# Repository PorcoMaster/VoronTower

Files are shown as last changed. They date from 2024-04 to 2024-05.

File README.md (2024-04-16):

# Voron Tower
A 4040 frame voron, with the possibility of a box and feet.

Biggest file cannot be uploaded on github, it's on this drive 
https://drive.google.com/file/d/1ePI7Y9nos1gBQOqrRFIDSbPcuf1UqJJw/view?usp=sharing

the file is completely parametric, i had to change the position of the rails, and a bunch of files, any question just ask, i intend to build this printer, so any feedback will be greatly appreciate, it's still some small stuff missing, but for a complete working printer, it should have all files necessary for the modification. 

files that i had to change z belt drive, z idler, z bearing block, zbearing block top, and z bearing block bottom became one, front idler top, front idler bottom, a/b driver, z chain lower mount, panel clip, and door clips. 

i believe the profile i have is the 4040 series 10, but i am not sure. 

i also changed the mgn9 on z to mgn12. i will build the first one as a 350x350, as i don't want to risk a 500x500 with a carriage with 2020, i believe everything else can be used from the original project from voron 2.4.R2

# CLICK ON THE IMAGE TO SEE THE VIDEO!!!

Watch the video (https://www.youtube.com/watch?v=f0kk1qKtl04)
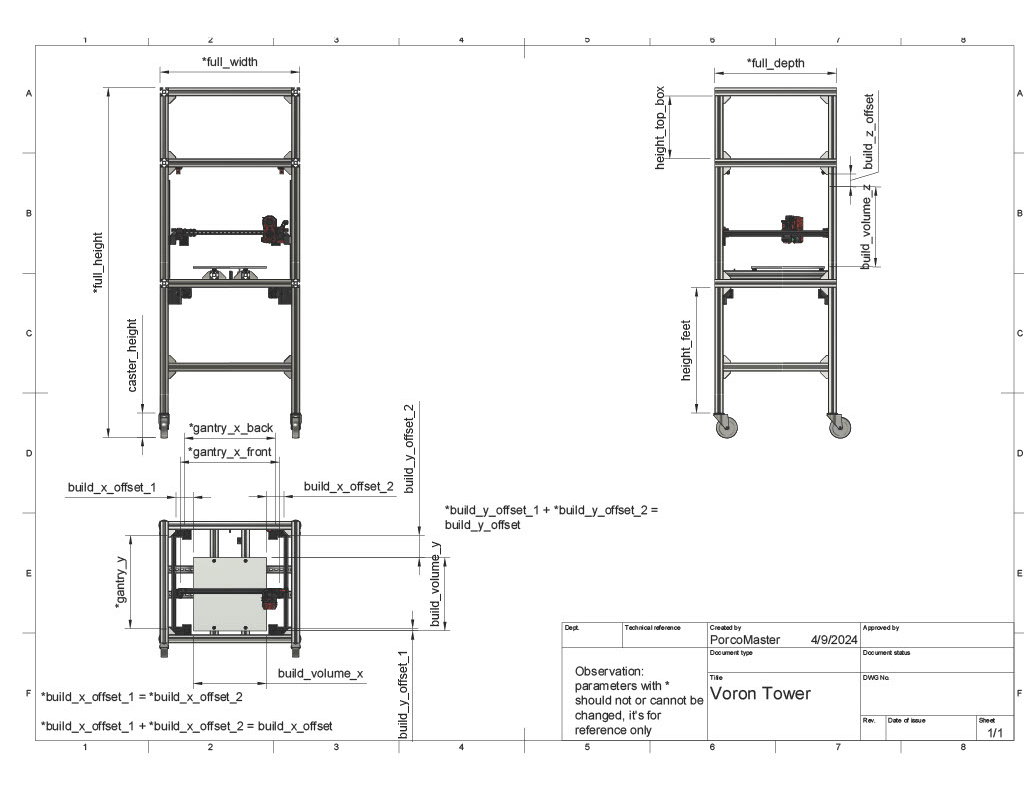
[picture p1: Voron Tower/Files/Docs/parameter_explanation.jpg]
parameters
[]
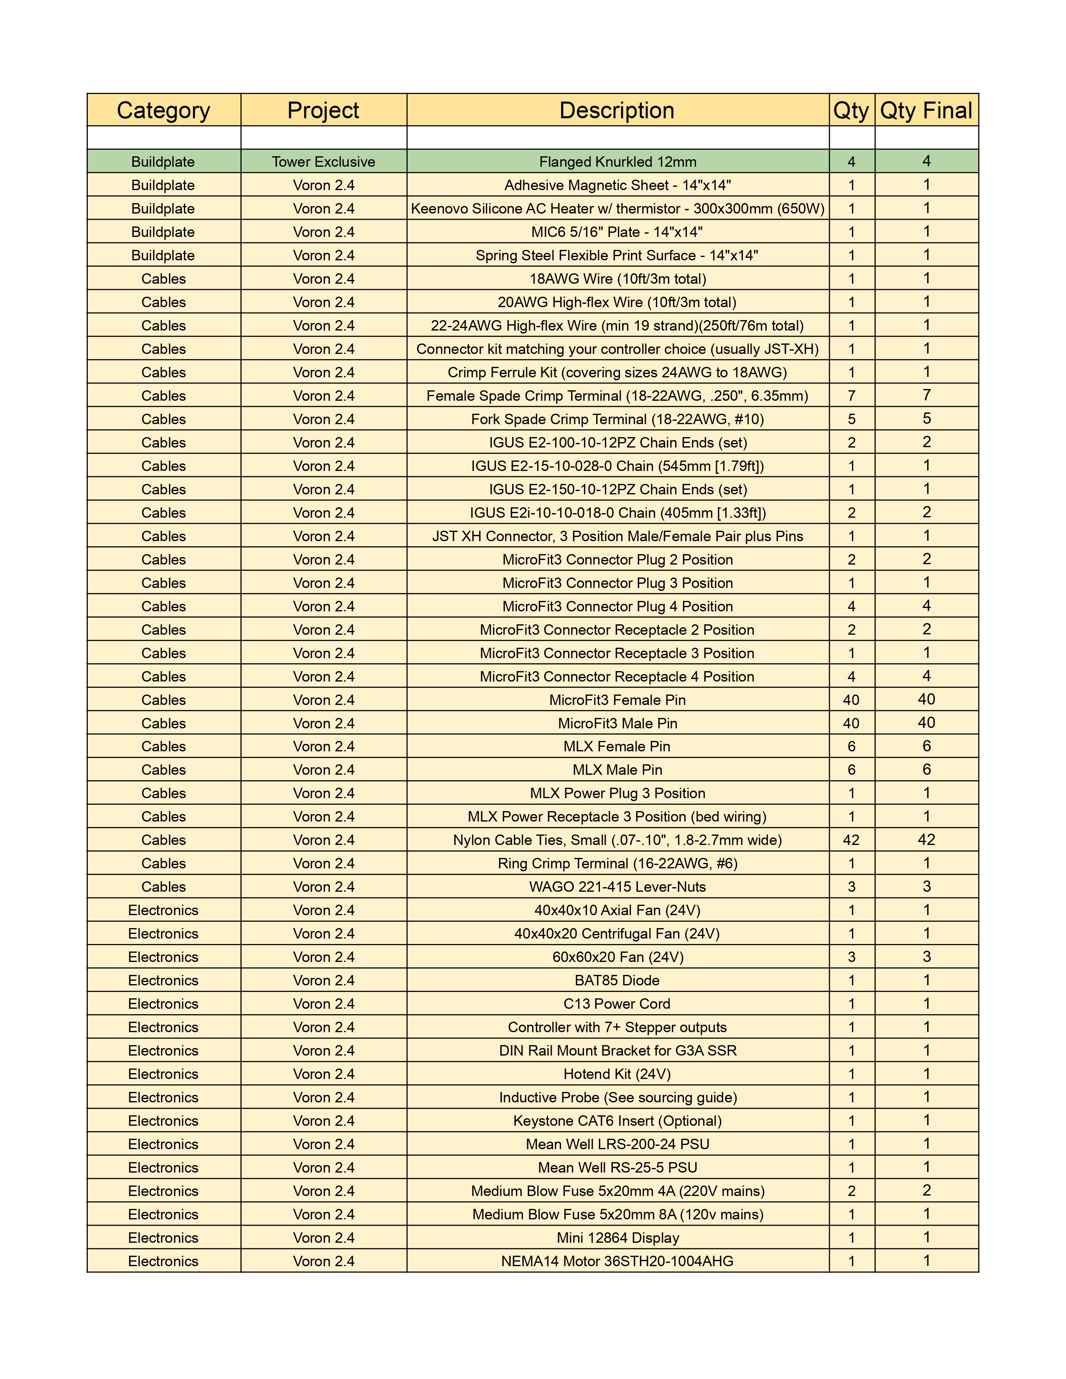
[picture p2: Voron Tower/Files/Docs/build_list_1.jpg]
list_1

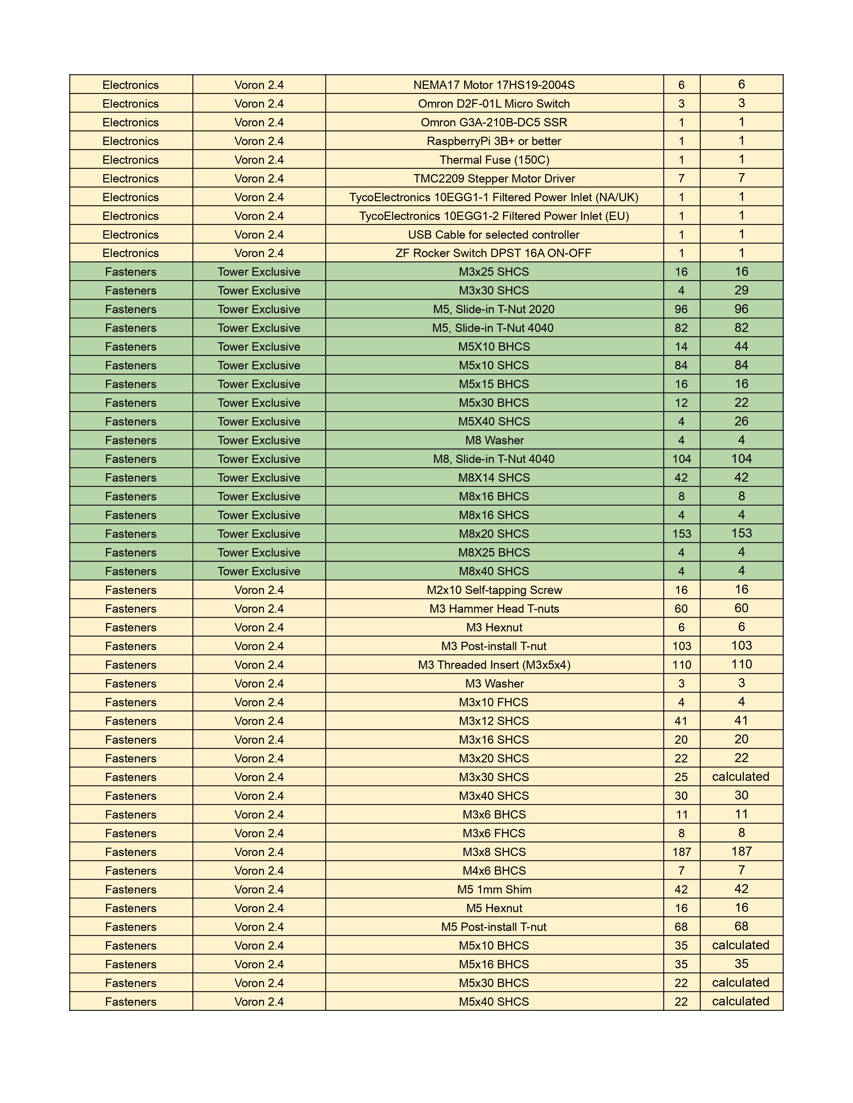
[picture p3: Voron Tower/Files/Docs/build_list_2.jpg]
list_2

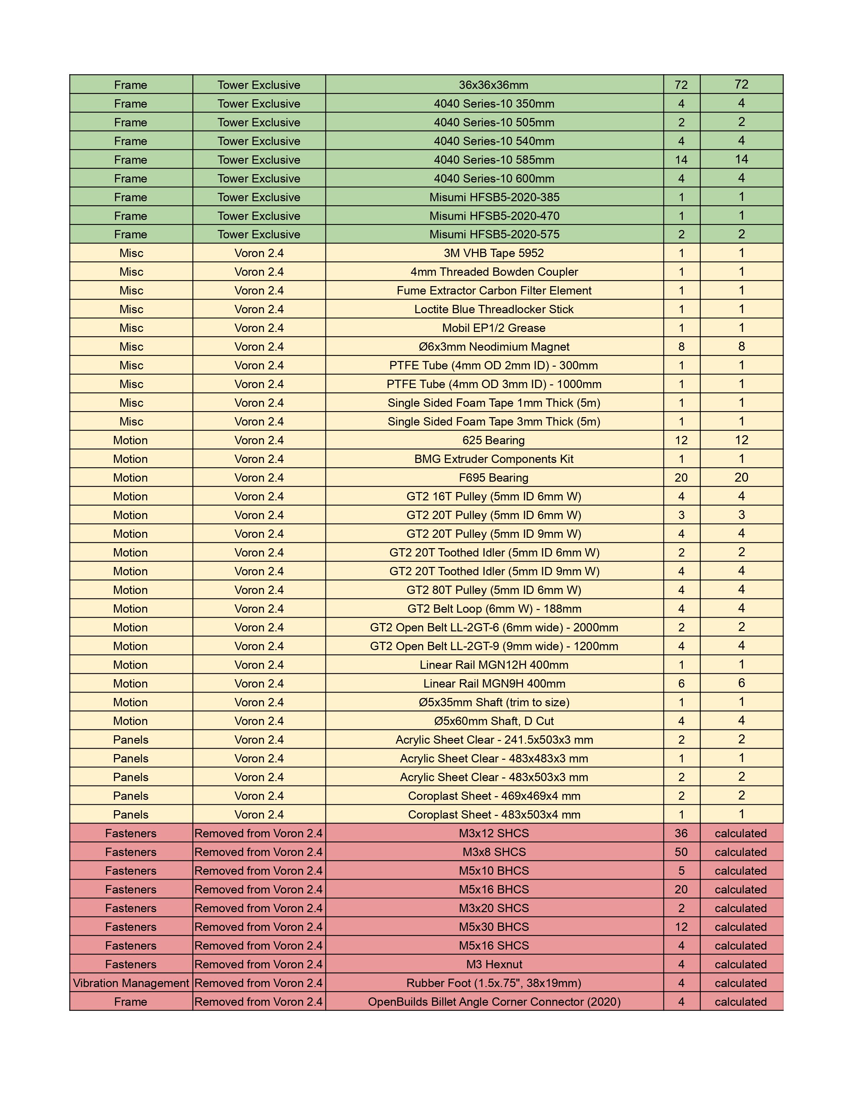
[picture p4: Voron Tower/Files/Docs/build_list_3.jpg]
list_3

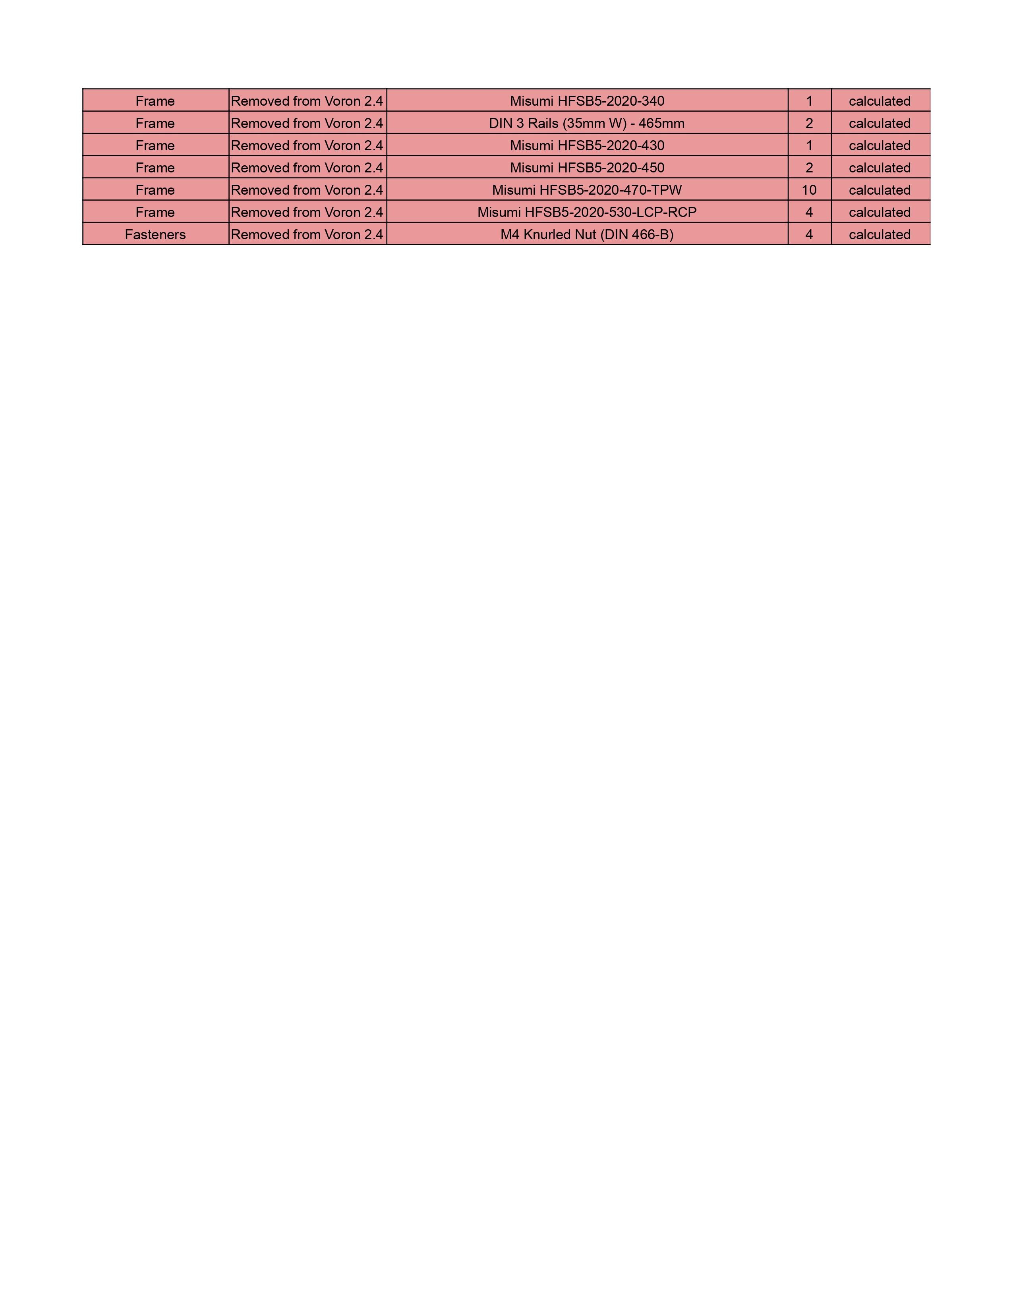
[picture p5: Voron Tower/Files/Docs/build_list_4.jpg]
list_4


#deprecated file: https://drive.google.com/file/d/1OqIFfqwKYdB3r7j7NeKnkWH7O517zN0H/view?usp=sharing

Update: 7 of april of 2024, there are some problems on the build volume and joints on the file, i am fixing it, i will release the fixed files in a few days, will add offset to add in top of the build volume that way you can add freee gantry movement without adding bed, also will add the full height, full width and full depth, also adding caster height to have full height better calculated.

update: 8 of april of 2024, several fixes, fixed all types of joints added some joint animations, i will add a video later on about it, fixed door clips, fixed build volume, put a image of parameter to make it easier to change and understand, added full height, full width, full depth, added build_x_y_z_offset.

update: 15 of april of 2024, a few more joints fixed, this fix are about the size of the gantry profiles, as they do have some work around on then i put up to 6 mm more or less. but you should not change more than 3 mm. if you do want to change change on gantry_x_front, gantry_x_back or gantry_y
also changed the sizes of gantry and overral so all gantrys were on good sizes to be cut, on older one you would find sizes like 572 mm or 673, now i changed so it has easy to cut sizes ending in 0 or 5, ie. 570,475 and so on. 
also changed build_x_offset to 47 mm, build_y_offset to 50 mm and build_z_offset to 24 mm, also i will add my first buy list.

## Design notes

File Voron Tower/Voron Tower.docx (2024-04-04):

Voron Tower

Things that were changed until now

Profiles on frames from 2020 to 4040

mgn12 instead of mgn9 on Z.

I think carriage I choose was mgn12-h, holes are 20mm vertical, and 20mm horizontal apart, center to center

I had to change the place the Z rails were put and to internals on X, instead of Z

Z belt drivers
Z idlers

z bearing block

Z bearing block top

Z bearing Block Bottom

front idler top
front idler bottom

A/B drivers both sides

Z chain lower mount

Panel Clip

door clips

concerns until now, the change of rail location and block top, as they had to be changed on friction or stability to the system

Front Idler A top, could have some improvements but I will let as it is for now, it looks practical, just not beautiful

parameters and projects concerns

I had to add a parameter for mgn_9 so it was easier to make all joints, however, I did not change the parameter on the rectangular pattern of holes in the mgn_9, it will not change anything if it goes wrong practically and on project, but might make it ugly depending on what changes on parameter mgn_9

I am not doing Z_belt cover for now, as I believe the space it has is already small enough, I can do one later thou, as it’s quite easy, I will just focus on other subjects for now.

I will not focus on this now, but later on I need to make a double panel clip for up and down for the box.

the glass I could make one until it get to the top on the sides, and maybe even removing one profile in the middle and making a giant door, or two sections of doors I will analyse this later

just checked, and the build volume is not correct, the Z volume is just 320 mm on the 350mm^3, and the X is 290mm, the Y is correct, but almost none giveaway I think I will give it at least 50 mm of giveway

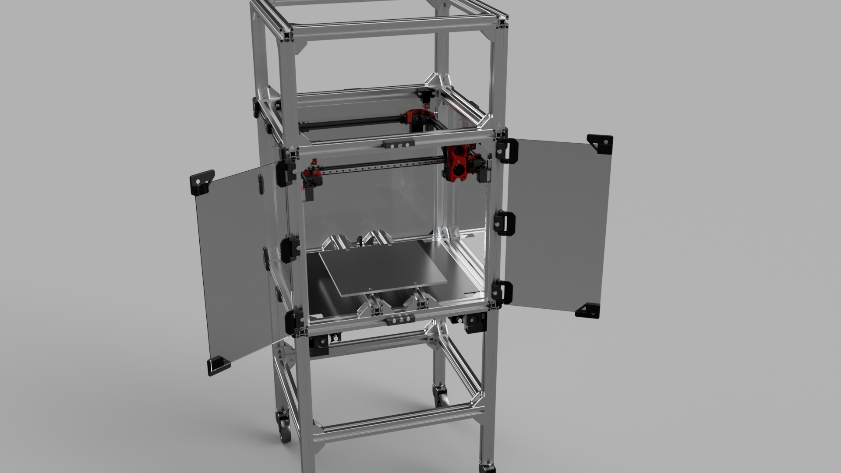
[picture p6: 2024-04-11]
Voron Tower/Files/Docs/Voron_Tower_2024.png

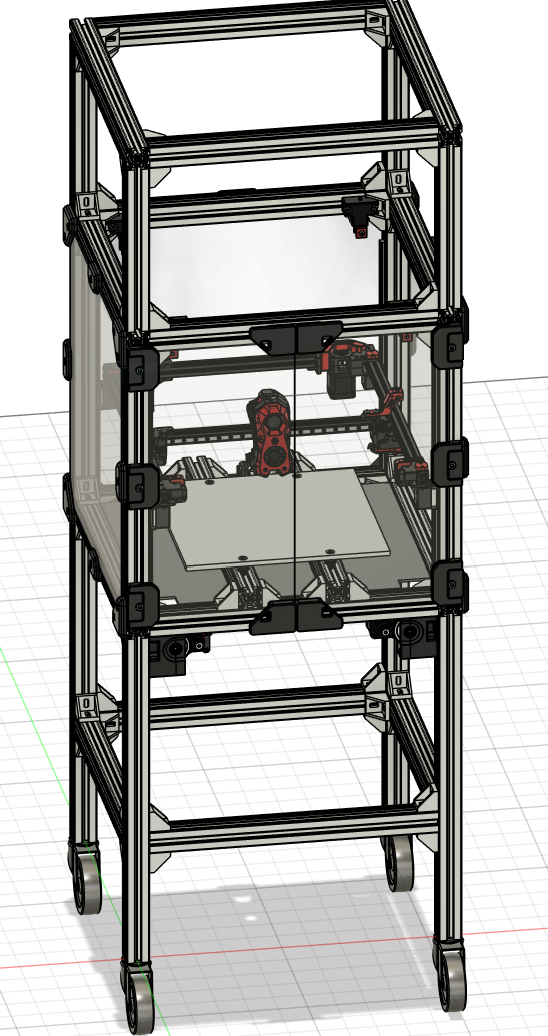
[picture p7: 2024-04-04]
Voron Tower/voron tower.png

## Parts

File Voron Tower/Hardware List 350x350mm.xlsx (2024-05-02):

Category | Project | Description | Qty | Qty Final
Buildplate | Tower Exclusive | Flanged Knurkled 12mm | 4 | 4
Buildplate | Voron 2.4 | Adhesive Magnetic Sheet - 14"x14" | 1 | 1
Buildplate | Voron 2.4 | Keenovo Silicone AC Heater w/ thermistor - 300x300mm (650W) | 1 | 1
Buildplate | Voron 2.4 | MIC6 5/16" Plate - 14"x14" | 1 | 1
Buildplate | Voron 2.4 | Spring Steel Flexible Print Surface - 14"x14" | 1 | 1
Cables | Voron 2.4 | 18AWG Wire (10ft/3m total) | 1 | 1
Cables | Voron 2.4 | 20AWG High-flex Wire (10ft/3m total) | 1 | 1
Cables | Voron 2.4 | 22-24AWG High-flex Wire (min 19 strand)(250ft/76m total) | 1 | 1
Cables | Voron 2.4 | Connector kit matching your controller choice (usually JST-XH) | 1 | 1
Cables | Voron 2.4 | Crimp Ferrule Kit (covering sizes 24AWG to 18AWG) | 1 | 1
Cables | Voron 2.4 | Female Spade Crimp Terminal (18-22AWG, .250", 6.35mm) | 7 | 7
Cables | Voron 2.4 | Fork Spade Crimp Terminal (18-22AWG, #10) | 5 | 5
Cables | Voron 2.4 | IGUS E2-100-10-12PZ Chain Ends (set) | 2 | 2
Cables | Voron 2.4 | IGUS E2-15-10-028-0 Chain (545mm [1.79ft]) | 1 | 1
Cables | Voron 2.4 | IGUS E2-150-10-12PZ Chain Ends (set) | 1 | 1
Cables | Voron 2.4 | IGUS E2i-10-10-018-0 Chain (405mm [1.33ft]) | 2 | 2
Cables | Voron 2.4 | JST XH Connector, 3 Position Male/Female Pair plus Pins | 1 | 1
Cables | Voron 2.4 | MicroFit3 Connector Plug 2 Position | 2 | 2
Cables | Voron 2.4 | MicroFit3 Connector Plug 3 Position | 1 | 1
Cables | Voron 2.4 | MicroFit3 Connector Plug 4 Position | 4 | 4
Cables | Voron 2.4 | MicroFit3 Connector Receptacle 2 Position | 2 | 2
Cables | Voron 2.4 | MicroFit3 Connector Receptacle 3 Position | 1 | 1
Cables | Voron 2.4 | MicroFit3 Connector Receptacle 4 Position | 4 | 4
Cables | Voron 2.4 | MicroFit3 Female Pin | 40 | 40
Cables | Voron 2.4 | MicroFit3 Male Pin | 40 | 40
Cables | Voron 2.4 | MLX Female Pin | 6 | 6
Cables | Voron 2.4 | MLX Male Pin | 6 | 6
Cables | Voron 2.4 | MLX Power Plug 3 Position | 1 | 1
Cables | Voron 2.4 | MLX Power Receptacle 3 Position (bed wiring) | 1 | 1
Cables | Voron 2.4 | Nylon Cable Ties, Small (.07-.10", 1.8-2.7mm wide) | 42 | 42
Cables | Voron 2.4 | Ring Crimp Terminal (16-22AWG, #6) | 1 | 1
Cables | Voron 2.4 | WAGO 221-415 Lever-Nuts | 3 | 3
Electronics | Voron 2.4 | 40x40x10 Axial Fan (24V) | 1 | 1
Electronics | Voron 2.4 | 40x40x20 Centrifugal Fan (24V) | 1 | 1
Electronics | Voron 2.4 | 60x60x20 Fan (24V) | 3 | 3
Electronics | Voron 2.4 | BAT85 Diode | 1 | 1
Electronics | Voron 2.4 | C13 Power Cord | 1 | 1
Electronics | Voron 2.4 | Controller with 7+ Stepper outputs | 1 | 1
Electronics | Voron 2.4 | DIN Rail Mount Bracket for G3A SSR | 1 | 1
Electronics | Voron 2.4 | Hotend Kit (24V) | 1 | 1
Electronics | Voron 2.4 | Inductive Probe (See sourcing guide) | 1 | 1
Electronics | Voron 2.4 | Keystone CAT6 Insert (Optional) | 1 | 1
Electronics | Voron 2.4 | Mean Well LRS-200-24 PSU | 1 | 1
Electronics | Voron 2.4 | Mean Well RS-25-5 PSU | 1 | 1
Electronics | Voron 2.4 | Medium Blow Fuse 5x20mm 4A (220V mains) | 2 | 2
Electronics | Voron 2.4 | Medium Blow Fuse 5x20mm 8A (120v mains) | 1 | 1
Electronics | Voron 2.4 | Mini 12864 Display | 1 | 1
Electronics | Voron 2.4 | NEMA14 Motor 36STH20-1004AHG | 1 | 1
Electronics | Voron 2.4 | NEMA17 Motor 17HS19-2004S | 6 | 6
Electronics | Voron 2.4 | Omron D2F-01L Micro Switch | 3 | 3
Electronics | Voron 2.4 | Omron G3A-210B-DC5 SSR | 1 | 1
Electronics | Voron 2.4 | RaspberryPi 3B+ or better | 1 | 1
Electronics | Voron 2.4 | Thermal Fuse (150C) | 1 | 1
Electronics | Voron 2.4 | TMC2209 Stepper Motor Driver | 7 | 7
Electronics | Voron 2.4 | TycoElectronics 10EGG1-1 Filtered Power Inlet (NA/UK) | 1 | 1
Electronics | Voron 2.4 | TycoElectronics 10EGG1-2 Filtered Power Inlet (EU) | 1 | 1
Electronics | Voron 2.4 | USB Cable for selected controller | 1 | 1
Electronics | Voron 2.4 | ZF Rocker Switch DPST 16A ON-OFF | 1 | 1
Fasteners | Tower Exclusive | M3x25 SHCS | 16 | 16
Fasteners | Tower Exclusive | M3x30 SHCS | 4 | 29
Fasteners | Tower Exclusive | M5, Slide-in T-Nut 2020 | 96 | 96
Fasteners | Tower Exclusive | M5, Slide-in T-Nut 4040 | 82 | 82
Fasteners | Tower Exclusive | M5X10 BHCS | 14 | 44
Fasteners | Tower Exclusive | M5x10 SHCS | 84 | 84
Fasteners | Tower Exclusive | M5x15 BHCS | 16 | 16
Fasteners | Tower Exclusive | M5x30 BHCS | 12 | 22
Fasteners | Tower Exclusive | M5X40 SHCS | 4 | 26
Fasteners | Tower Exclusive | M8 Washer | 4 | 4
Fasteners | Tower Exclusive | M8, Slide-in T-Nut 4040 | 104 | 104
Fasteners | Tower Exclusive | M8X14 SHCS | 42 | 42
Fasteners | Tower Exclusive | M8x16 BHCS | 8 | 8
Fasteners | Tower Exclusive | M8x16 SHCS | 4 | 4
Fasteners | Tower Exclusive | M8x20 SHCS | 153 | 153
Fasteners | Tower Exclusive | M8X25 BHCS | 4 | 4
Fasteners | Tower Exclusive | M8x40 SHCS | 4 | 4
Fasteners | Voron 2.4 | M2x10 Self-tapping Screw | 16 | 16
Fasteners | Voron 2.4 | M3 Hammer Head T-nuts | 60 | 60
Fasteners | Voron 2.4 | M3 Hexnut | 6 | 6
Fasteners | Voron 2.4 | M3 Post-install T-nut | 103 | 103
Fasteners | Voron 2.4 | M3 Threaded Insert (M3x5x4) | 110 | 110
Fasteners | Voron 2.4 | M3 Washer | 3 | 3
Fasteners | Voron 2.4 | M3x10 FHCS | 4 | 4
Fasteners | Voron 2.4 | M3x12 SHCS | 41 | 41
Fasteners | Voron 2.4 | M3x16 SHCS | 20 | 20
Fasteners | Voron 2.4 | M3x20 SHCS | 22 | 22
Fasteners | Voron 2.4 | M3x30 SHCS | 25 | calculated
Fasteners | Voron 2.4 | M3x40 SHCS | 30 | 30
Fasteners | Voron 2.4 | M3x6 BHCS | 11 | 11
Fasteners | Voron 2.4 | M3x6 FHCS | 8 | 8
Fasteners | Voron 2.4 | M3x8 SHCS | 187 | 187
Fasteners | Voron 2.4 | M4x6 BHCS | 7 | 7
Fasteners | Voron 2.4 | M5 1mm Shim | 42 | 42
Fasteners | Voron 2.4 | M5 Hexnut | 16 | 16
Fasteners | Voron 2.4 | M5 Post-install T-nut | 68 | 68
Fasteners | Voron 2.4 | M5x10 BHCS | 35 | calculated
Fasteners | Voron 2.4 | M5x16 BHCS | 35 | 35
Fasteners | Voron 2.4 | M5x30 BHCS | 22 | calculated
Fasteners | Voron 2.4 | M5x40 SHCS | 22 | calculated
Frame | Tower Exclusive | 36x36x36mm | 72 | 72
Frame | Tower Exclusive | 4040 Series-10 350mm | 4 | 4
Frame | Tower Exclusive | 4040 Series-10 510mm | 2 | 2
Frame | Tower Exclusive | 4040 Series-10 540mm | 4 | 4
Frame | Tower Exclusive | 4040 Series-10 590mm | 16 | 16
Frame | Tower Exclusive | 4040 Series-10 640mm | 4 | 4
Frame | Tower Exclusive | Misumi HFSB5-2020-390 | 1 | 1
Frame | Tower Exclusive | Misumi HFSB5-2020-475 | 1 | 1
Frame | Tower Exclusive | Misumi HFSB5-2020-580 | 2 | 2
Misc | Voron 2.4 | 3M VHB Tape 5952 | 1 | 1
Misc | Voron 2.4 | 4mm Threaded Bowden Coupler | 1 | 1
Misc | Voron 2.4 | Fume Extractor Carbon Filter Element | 1 | 1
Misc | Voron 2.4 | Loctite Blue Threadlocker Stick | 1 | 1
Misc | Voron 2.4 | Mobil EP1/2 Grease | 1 | 1
Misc | Voron 2.4 | Ø6x3mm Neodimium Magnet | 8 | 8
Misc | Voron 2.4 | PTFE Tube (4mm OD 2mm ID) - 300mm | 1 | 1
Misc | Voron 2.4 | PTFE Tube (4mm OD 3mm ID) - 1000mm | 1 | 1
Misc | Voron 2.4 | Single Sided Foam Tape 1mm Thick (5m) | 1 | 1
Misc | Voron 2.4 | Single Sided Foam Tape 3mm Thick (5m) | 1 | 1
Motion | Voron 2.4 | 625 Bearing | 12 | 12
Motion | Voron 2.4 | BMG Extruder Components Kit | 1 | 1
Motion | Voron 2.4 | F695 Bearing | 20 | 20
Motion | Voron 2.4 | GT2 16T Pulley (5mm ID 6mm W) | 4 | 4
Motion | Voron 2.4 | GT2 20T Pulley (5mm ID 6mm W) | 3 | 3
Motion | Voron 2.4 | GT2 20T Pulley (5mm ID 9mm W) | 4 | 4
Motion | Voron 2.4 | GT2 20T Toothed Idler (5mm ID 6mm W) | 2 | 2
Motion | Voron 2.4 | GT2 20T Toothed Idler (5mm ID 9mm W) | 4 | 4
Motion | Voron 2.4 | GT2 80T Pulley (5mm ID 6mm W) | 4 | 4
Motion | Voron 2.4 | GT2 Belt Loop (6mm W) - 188mm | 4 | 4
Motion | Voron 2.4 | GT2 Open Belt LL-2GT-6 (6mm wide) - 2000mm | 2 | 2
Motion | Voron 2.4 | GT2 Open Belt LL-2GT-9 (9mm wide) - 1200mm | 4 | 4
Motion | Voron 2.4 | Linear Rail MGN12H 400mm | 1 | 1
Motion | Voron 2.4 | Linear Rail MGN9H 400mm | 6 | 6
Motion | Voron 2.4 | Ø5x35mm Shaft (trim to size) | 1 | 1
Motion | Voron 2.4 | Ø5x60mm Shaft, D Cut | 4 | 4
Panels | Voron 2.4 | Acrylic Sheet Clear - 241.5x503x3 mm | 2 | 2
Panels | Voron 2.4 | Acrylic Sheet Clear - 483x483x3 mm | 1 | 1
Panels | Voron 2.4 | Acrylic Sheet Clear - 483x503x3 mm | 2 | 2
Panels | Voron 2.4 | Coroplast Sheet - 469x469x4 mm | 2 | 2
Panels | Voron 2.4 | Coroplast Sheet - 483x503x4 mm | 1 | 1
Fasteners | Removed from Voron 2.4 | M3x12 SHCS | 36 | calculated
Fasteners | Removed from Voron 2.4 | M3x8 SHCS | 50 | calculated
Fasteners | Removed from Voron 2.4 | M5x10 BHCS | 5 | calculated
Fasteners | Removed from Voron 2.4 | M5x16 BHCS | 20 | calculated
Fasteners | Removed from Voron 2.4 | M3x20 SHCS | 2 | calculated
Fasteners | Removed from Voron 2.4 | M5x30 BHCS | 12 | calculated
Fasteners | Removed from Voron 2.4 | M5x16 SHCS | 4 | calculated
Fasteners | Removed from Voron 2.4 | M3 Hexnut | 4 | calculated
Vibration Management | Removed from Voron 2.4 | Rubber Foot (1.5x.75", 38x19mm) | 4 | calculated
Frame | Removed from Voron 2.4 | OpenBuilds Billet Angle Corner Connector (2020) | 4 | calculated
Frame | Removed from Voron 2.4 | Misumi HFSB5-2020-340 | 1 | calculated
Frame | Removed from Voron 2.4 | DIN 3 Rails (35mm W) - 465mm | 2 | calculated
Frame | Removed from Voron 2.4 | Misumi HFSB5-2020-430 | 1 | calculated
Frame | Removed from Voron 2.4 | Misumi HFSB5-2020-450 | 2 | calculated
Frame | Removed from Voron 2.4 | Misumi HFSB5-2020-470-TPW | 10 | calculated
Frame | Removed from Voron 2.4 | Misumi HFSB5-2020-530-LCP-RCP | 4 | calculated
Fasteners | Removed from Voron 2.4 | M4 Knurled Nut (DIN 466-B) | 4 | calculated

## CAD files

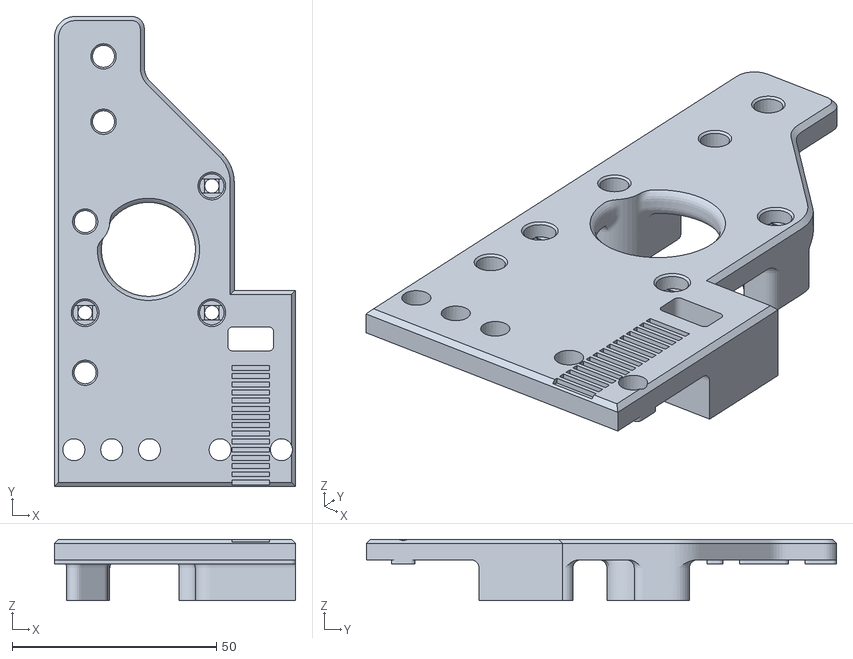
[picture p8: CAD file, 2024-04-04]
Voron Tower/Files/Stl/A B Drive/b_drive_1.stl
59.0 x 115.0 x 15.0

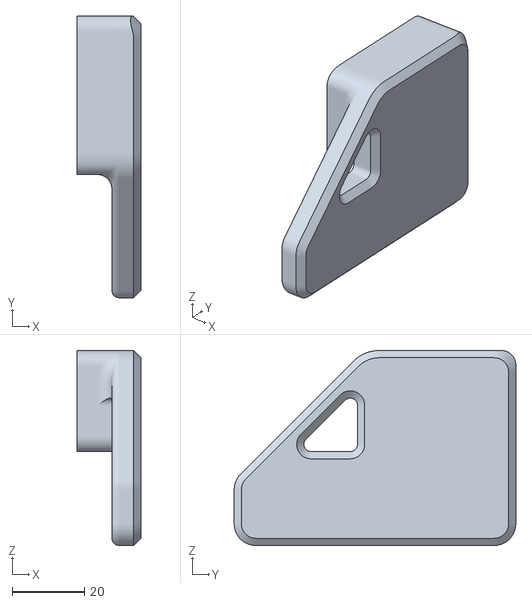
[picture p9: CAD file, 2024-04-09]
Voron Tower/Files/Stl/Door Clips/door_handle_b_4040.stl
17.6 x 78.0 x 54.0

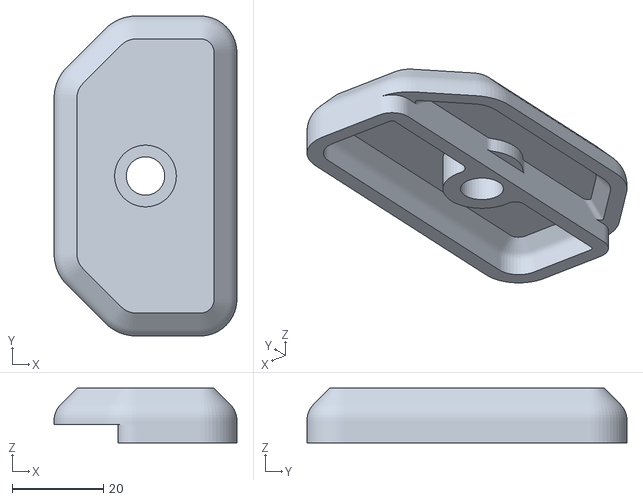
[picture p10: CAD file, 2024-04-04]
Voron Tower/Files/Stl/Panel Clips/midspan_clip_4040.stl
40.0 x 70.0 x 12.0

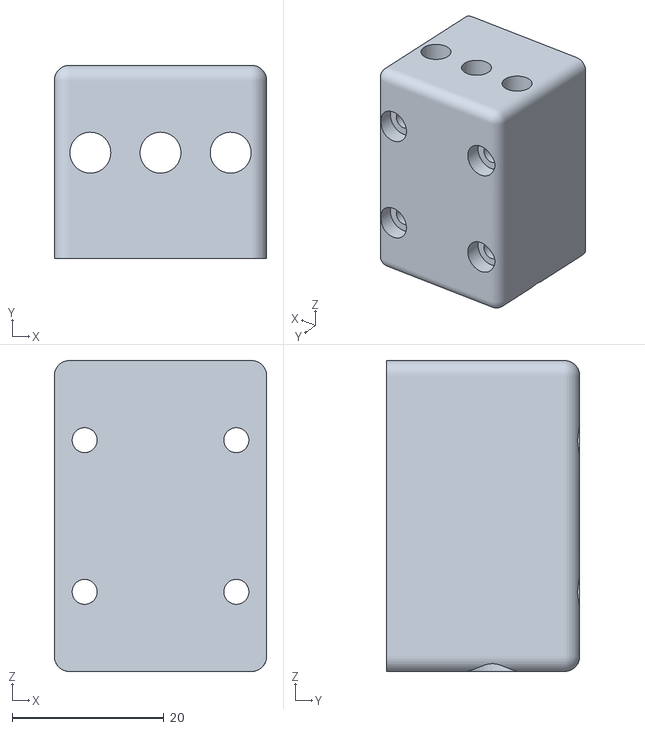
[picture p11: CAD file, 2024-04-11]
Voron Tower/Files/Stl/Z Bearing/z_bearing_block_v8.stl
28.0 x 25.5 x 41.0

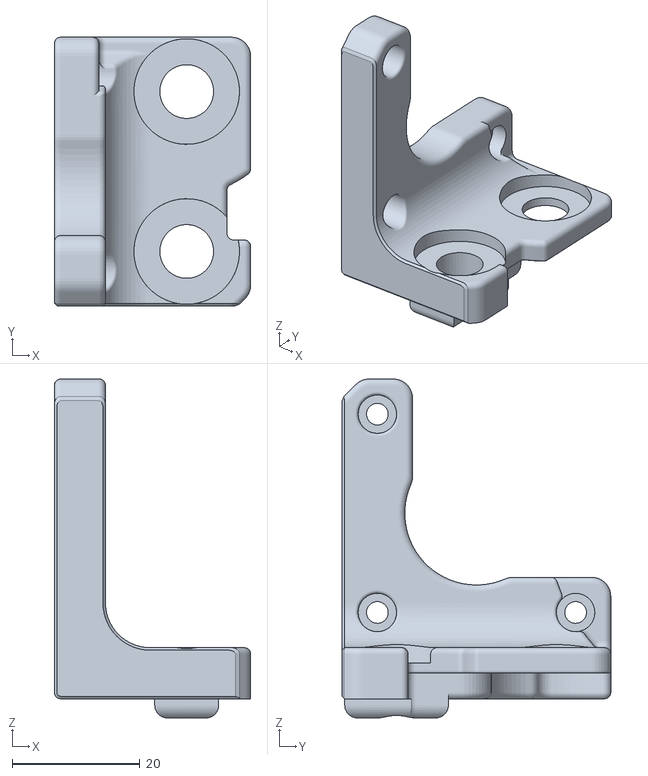
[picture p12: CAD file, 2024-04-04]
Voron Tower/Files/Stl/Z Belt Driver for 4040/z_motor_mount_a.stl
30.7 x 42.0 x 53.0

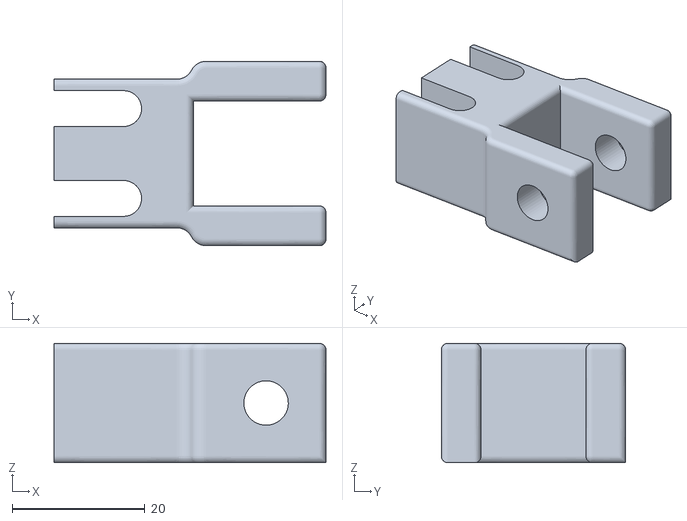
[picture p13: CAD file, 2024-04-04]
Voron Tower/Files/Stl/Z idler 4040/z_idler_4040_2_b.stl
41.0 x 27.8 x 18.0

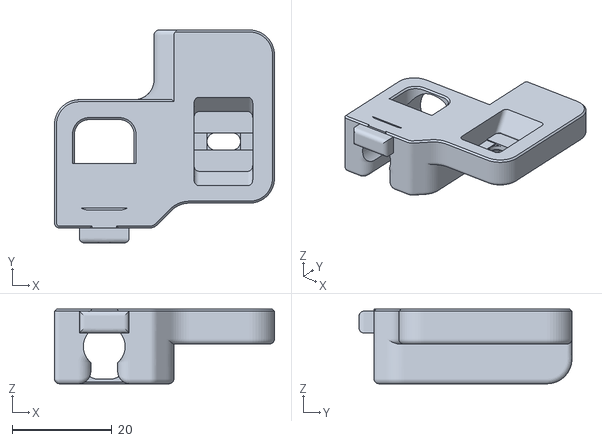
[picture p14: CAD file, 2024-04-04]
Voron Tower/Files/Stl/z_chain_lower_mount.stl
44.2 x 42.8 x 15.0

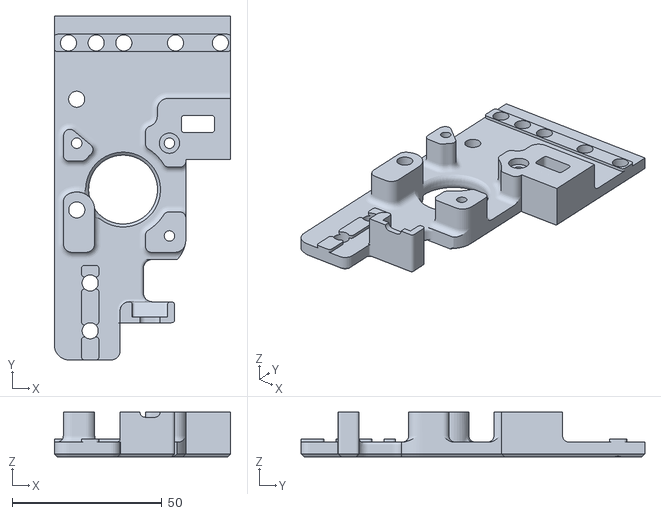
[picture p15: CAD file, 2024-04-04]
Voron Tower/Files/Stl/A B Drive/a_drive_2.stl
59.0 x 115.0 x 15.0

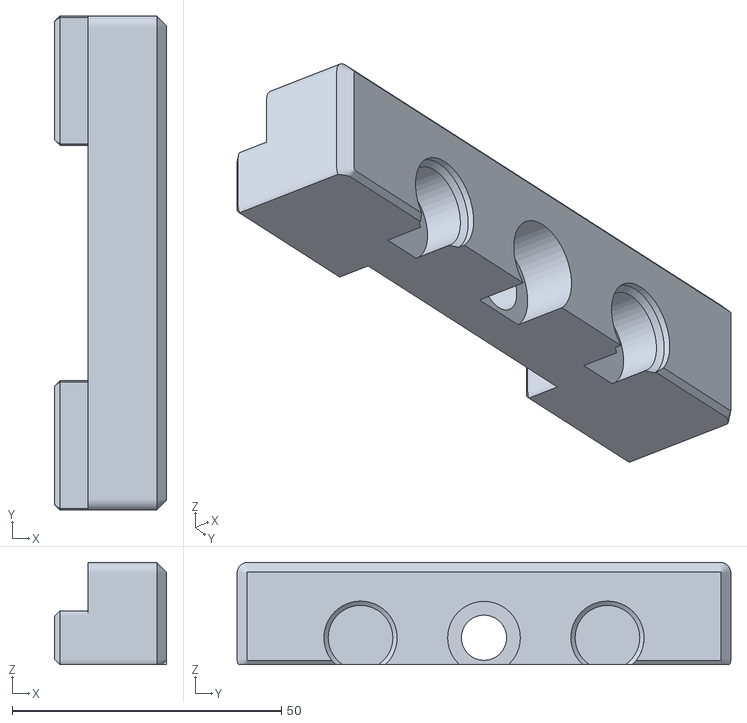
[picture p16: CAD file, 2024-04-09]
Voron Tower/Files/Stl/Door Clips/door_latch_magnet_4040.stl
20.8 x 91.7 x 19.0

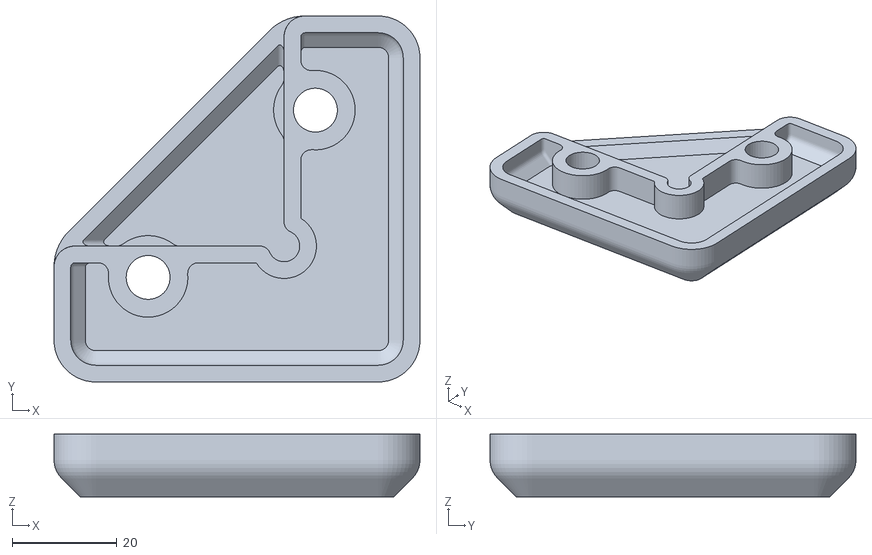
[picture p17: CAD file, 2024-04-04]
Voron Tower/Files/Stl/Panel Clips/corner_clip_4040.stl
70.0 x 70.0 x 12.0

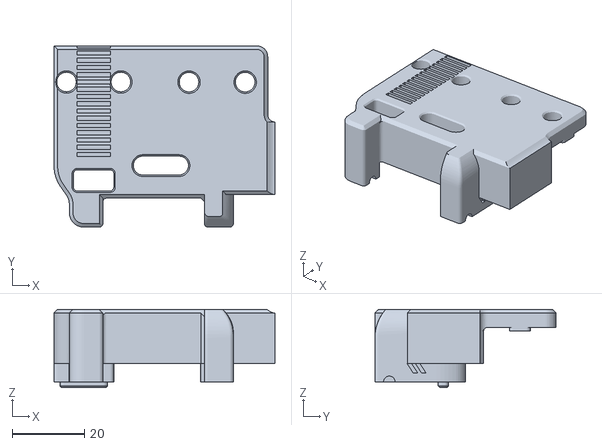
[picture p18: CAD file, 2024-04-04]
Voron Tower/Files/Stl/Z Bearing/front_idler_top_b.stl
61.0 x 50.0 x 21.6

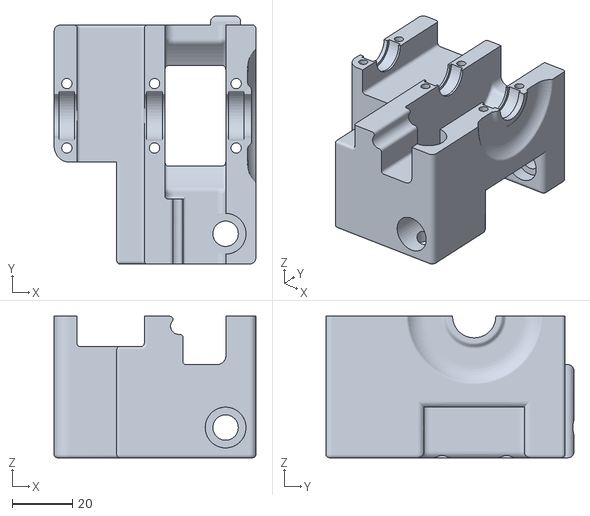
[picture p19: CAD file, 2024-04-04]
Voron Tower/Files/Stl/Z Belt Driver for 4040/z_belt_driver_b_1.stl
66.7 x 82.0 x 46.8

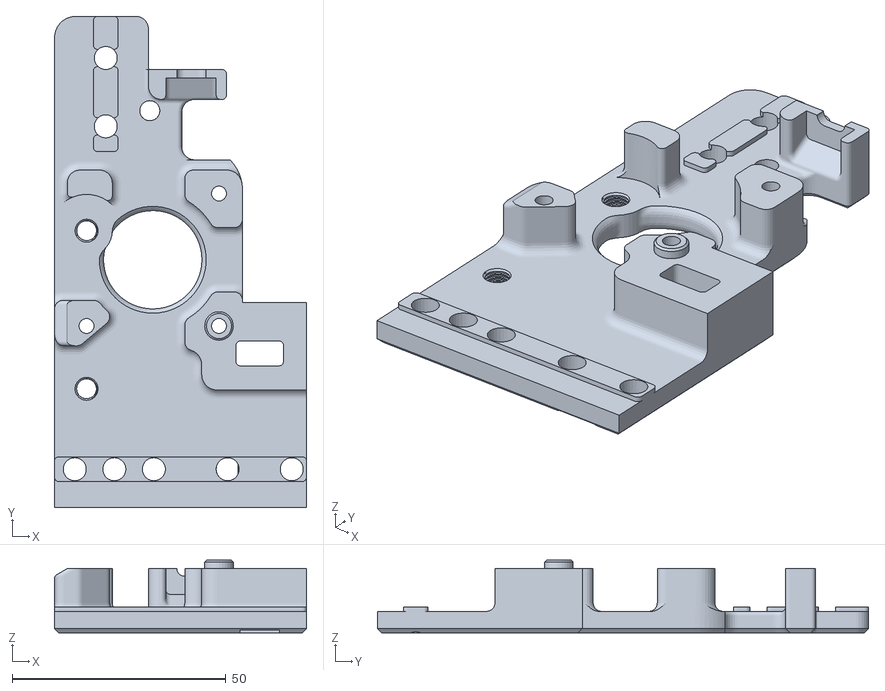
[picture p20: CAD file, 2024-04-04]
Voron Tower/Files/Stl/A B Drive/a_drive_1.stl
59.0 x 115.0 x 17.0

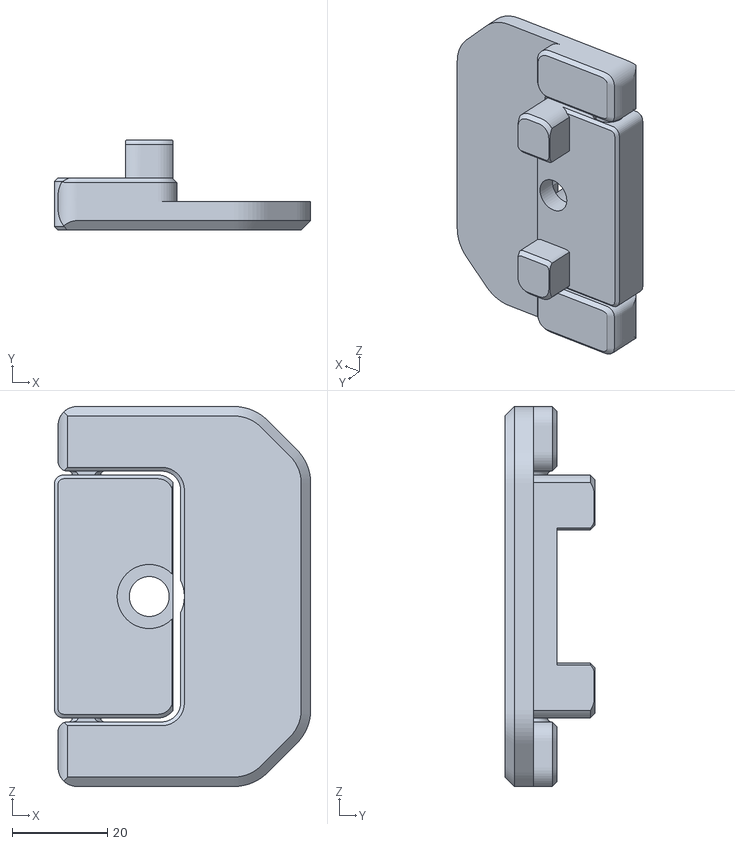
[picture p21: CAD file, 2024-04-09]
Voron Tower/Files/Stl/Door Clips/door_hinge_4040.stl
54.0 x 19.0 x 80.0

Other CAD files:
Voron Tower/Files/Stl/Z idler 4040/z_idler_4040_2_a.stl
Voron Tower/Files/Stl/Z Bearing/front_idler_bottom_b_1.stl
Voron Tower/Files/Stl/Z Belt Driver for 4040/z_belt_driver_b_2.stl
Voron Tower/Files/Stl/Z idler 4040/z_idler_4040_1_b.stl
Voron Tower/Files/Fusion Files/Deprecated/Z Bearing Block v5.f3d
Voron Tower/Files/Fusion Files/Deprecated/door clips v3.f3d
Voron Tower/Files/Fusion Files/Door Handle v5.f3d
Voron Tower/Files/Fusion Files/Door Hinge 4040 v8.f3d
Voron Tower/Files/Fusion Files/Door Latch Magnet v4.f3d
Voron Tower/Files/Fusion Files/Front Idler Bottom v11.f3z
Voron Tower/Files/Fusion Files/Panel Clip v3.f3d
Voron Tower/Files/Fusion Files/Z Bearing Block v5.f3d
Voron Tower/Files/Fusion Files/Z Bearing Block v8.f3d
Voron Tower/Files/Fusion Files/door clips v3.f3d
Voron Tower/Files/Fusion Files/z chain lower mount v1.f3d
Voron Tower/Files/Stl/A B Drive/b_drive_2.stl
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

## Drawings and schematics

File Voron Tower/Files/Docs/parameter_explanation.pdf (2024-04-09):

# caster_height

*gantry_y | *gantry_x_back

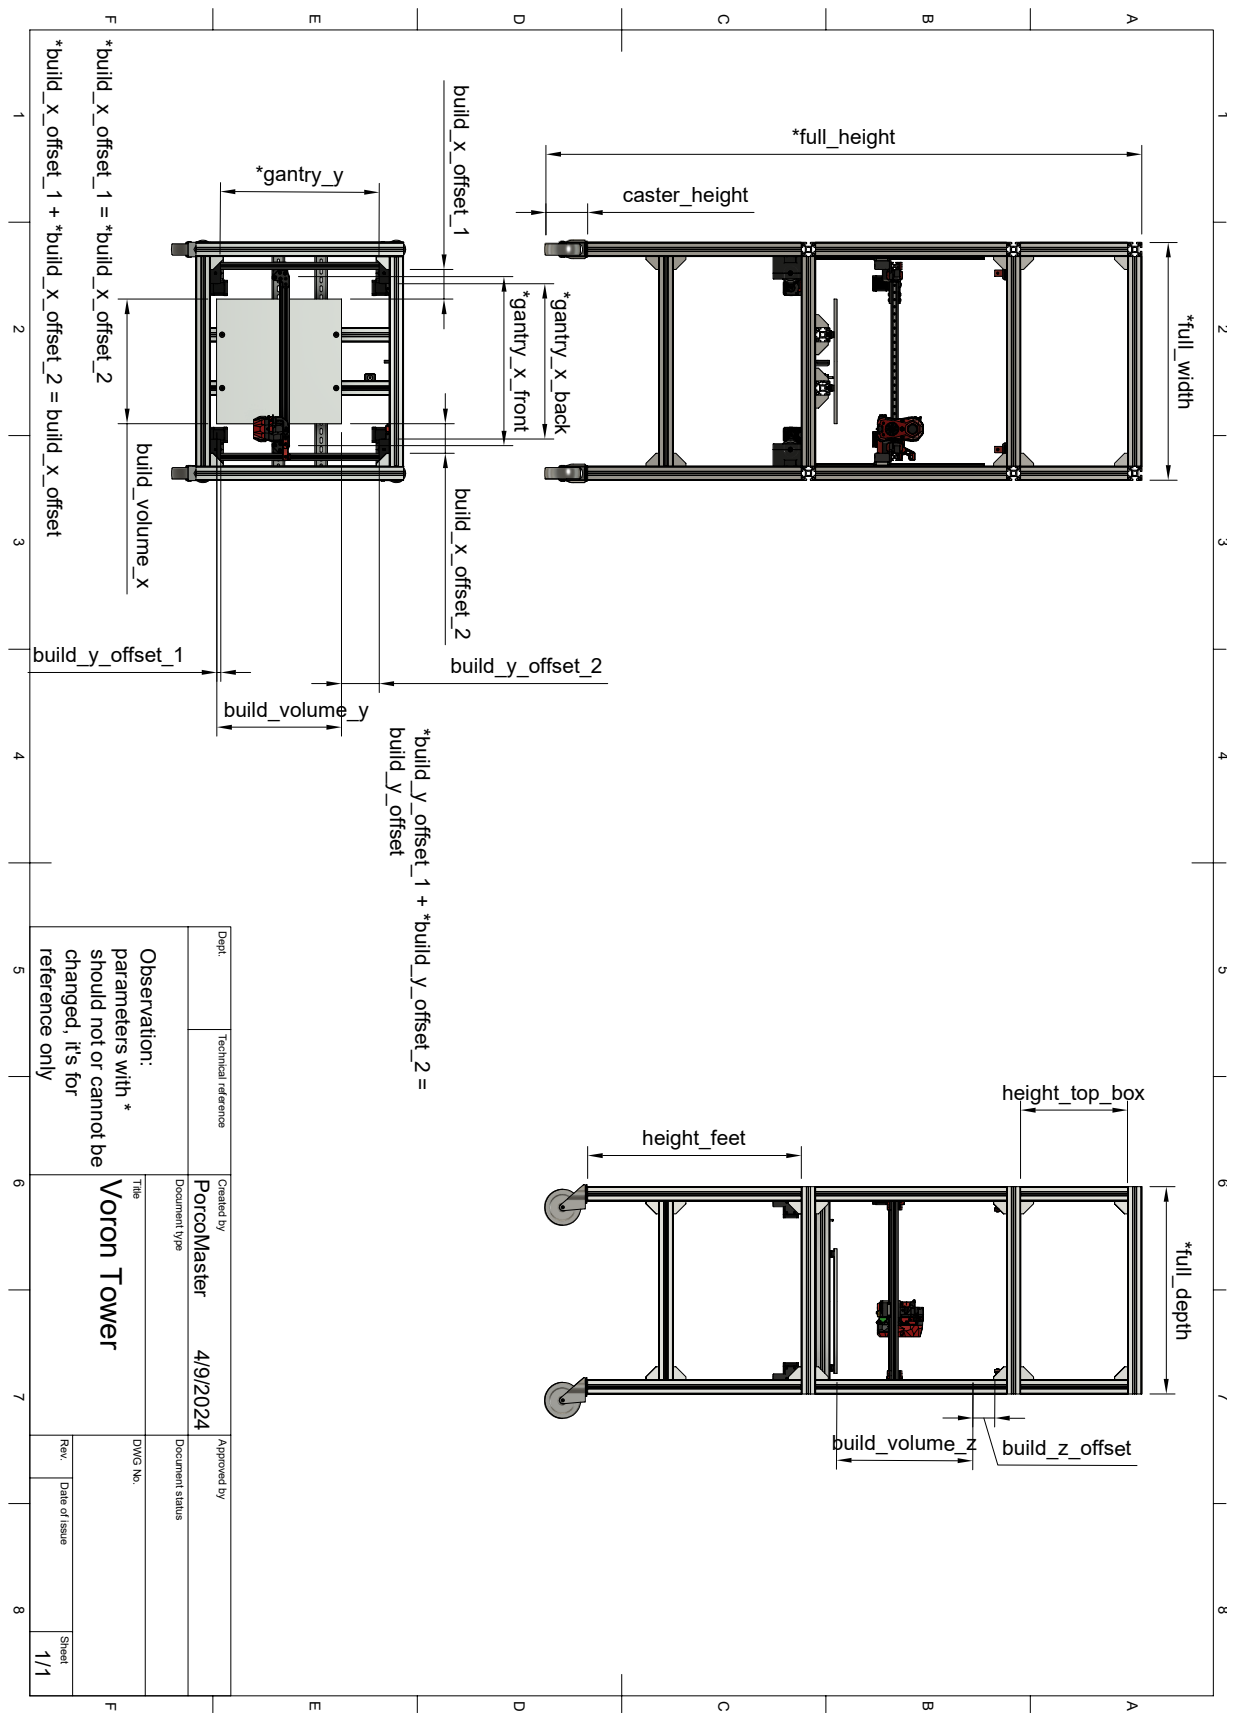
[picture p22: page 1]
2 3 4 5 6 7 8 1 2 3 4 5 6 7 8 FED; FED; build_volume_y build_volume_x; height_feet; build_volume_z build_z_offset build_x_offset_1 build_x_offset_2 *build_x_offset_1 + *build_x_offset_2 = build_x_offset; *build_x_offset_1 = *build_x_offset_2; build_y_offset_1; build_y_offset_2 build_y_offset *build_y_offset_1 + *build_y_offset_2 =; *full_height; *full_width *full_depth *gantry_x_front

A Dept. Technical reference Created by Approved by Title DWG No. Document type Document status Rev. Date of issue Sheet 4/9/2024 1/1 Voron Tower PorcoMaster
height_top_box reference only changed, it's for should not or cannot be parameters with * Observation:

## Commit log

2024-04-04 new files
    [Front Idler Bottom v11.f3z, Panel Clip v3.f3d, Z Bearing Block v5.f3d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]
2024-04-09 door clips update
    updated and fixed door clips
    [door clips v3.f3d, door_handle_a.stl, door_handle_b.stl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]
2024-04-09 fixes, and additions
    adding build_volume_offset, fixing several mistakes, adding door hinger fixes. fix in several joints
    [Door Handle v5.f3d, Door Hinge 4040 v8.f3d, Door Latch Magnet v4.f3d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]
2024-04-11 Z_bearing_block updated
    the z bearing block, would need a m5x24mm, and that would be too hard to find, and would need washers to make it perfect.
    so i added 1.5 mm to the end so a m5x25mm would fit perfectly and would still give you 1mm of space between the end of the rail
    [Z Bearing Block v5.f3d, Z Bearing Block v8.f3d, z_bearing_block.stl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]
2024-04-16 several updates and fixes
    several updates on joints and some fixes here and there, explained on readme on 15 of april of 2024
    [Hardware List 350x350mm.xlsx]
2024-05-02 changed a few things on the hardware list
    changed hardware the complete size to 355x355x350, as most beds sold in the market are 355x355mm instead of 350x350mm. so i prefer to just add 5mm overrall, also i made a mistake and calculate just 14 bars of 585, and it was actually 16 bars, so i changed on the list to 16 bars of 590mm, also changed the sized on 2020 gantry to accomodate this changes.
    [Hardware List 350x350mm.xlsx]
2024-05-02 Update Hardware List 350x350mm.xlsx
    changed feet to 640mm instead of 600mm
    [Hardware List 350x350mm.xlsx]
